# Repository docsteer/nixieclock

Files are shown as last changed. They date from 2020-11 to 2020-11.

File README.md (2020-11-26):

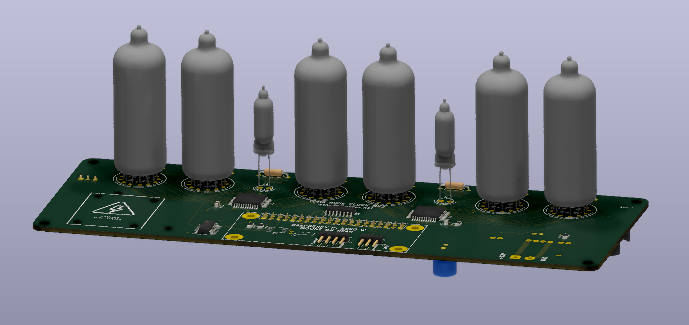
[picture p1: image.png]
Image of Clock


# Toms Nixie Clock
This project includes software and hardware designs for a nixie clock based on Raspberry Pi Zero W and IN14 tubes.

The design has hour, minute and second displays, separator digits (IN-1 indicators), and RGB LED underlighting of the tubes.

# Hardware
The hardware folder includes the PCB design files (KiCad format), and a bill of materials with component links to Mouser electronics.

# Software
The software is a Python script that runs on a standard installation of Raspian on a raspberry pi zero W.

It drives the tubes, and controls the LED underlighting based on astrononical time, pre-dawn, after dawn, after noon, after sunset)

It requires the following libraries (which you can install with ```pip install xxx```):

- spidev
- astral
- pytz
- neopixel

# Enclosure
The enclosure design is for laser-cut plywood with suitable openings for the tubes, indicators and support hardware

# License
This project is licensed under a Creative Commons Zero license. Feel free to remix and use as you please.

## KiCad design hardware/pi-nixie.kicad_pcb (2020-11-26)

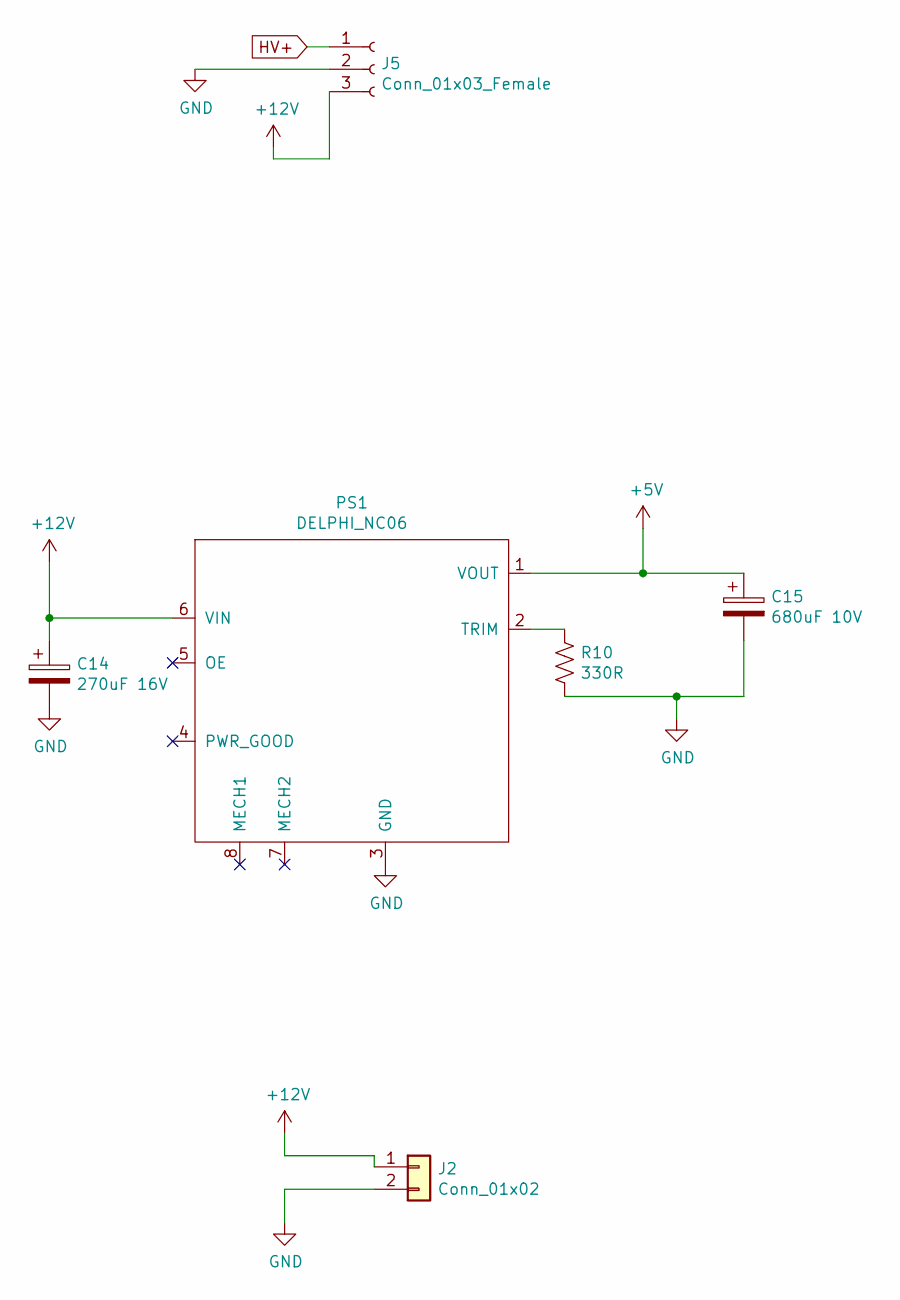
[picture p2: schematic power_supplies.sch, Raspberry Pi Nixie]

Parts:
C14: 270uF 16V; CP_Radial_D6.3mm_P2.50mm; Mouser P/N 232-16ZLJ270M6.3X11
C15: 680uF 10V; CP_Radial_D8.0mm_P3.50mm; Mouser P/N 710-860010274013
J2: Conn_01x02; SolderWirePad_1x02_P5.08mm_Drill1.5mm
J5: Conn_01x03_Female; PinHeader_1x03_P2.54mm_Vertical
PS1: DELPHI_NC06; DELPHI_NC06_REGULATOR
R10: 330R; R_1206_3216Metric_Pad1.42x1.75mm_HandSolder

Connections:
+5V: C15.1, PS1.1 (VOUT); also elsewhere on the board
+12V: C14.1, J2.1, J5.3, PS1.6 (VIN); also elsewhere on the board
GND: C14.2, C15.2, J2.2, J5.2, PS1.3 (GND), R10.2; also elsewhere on the board
HV+: J5.1; also elsewhere on the board
unnamed: PS1.2 (TRIM), R10.1

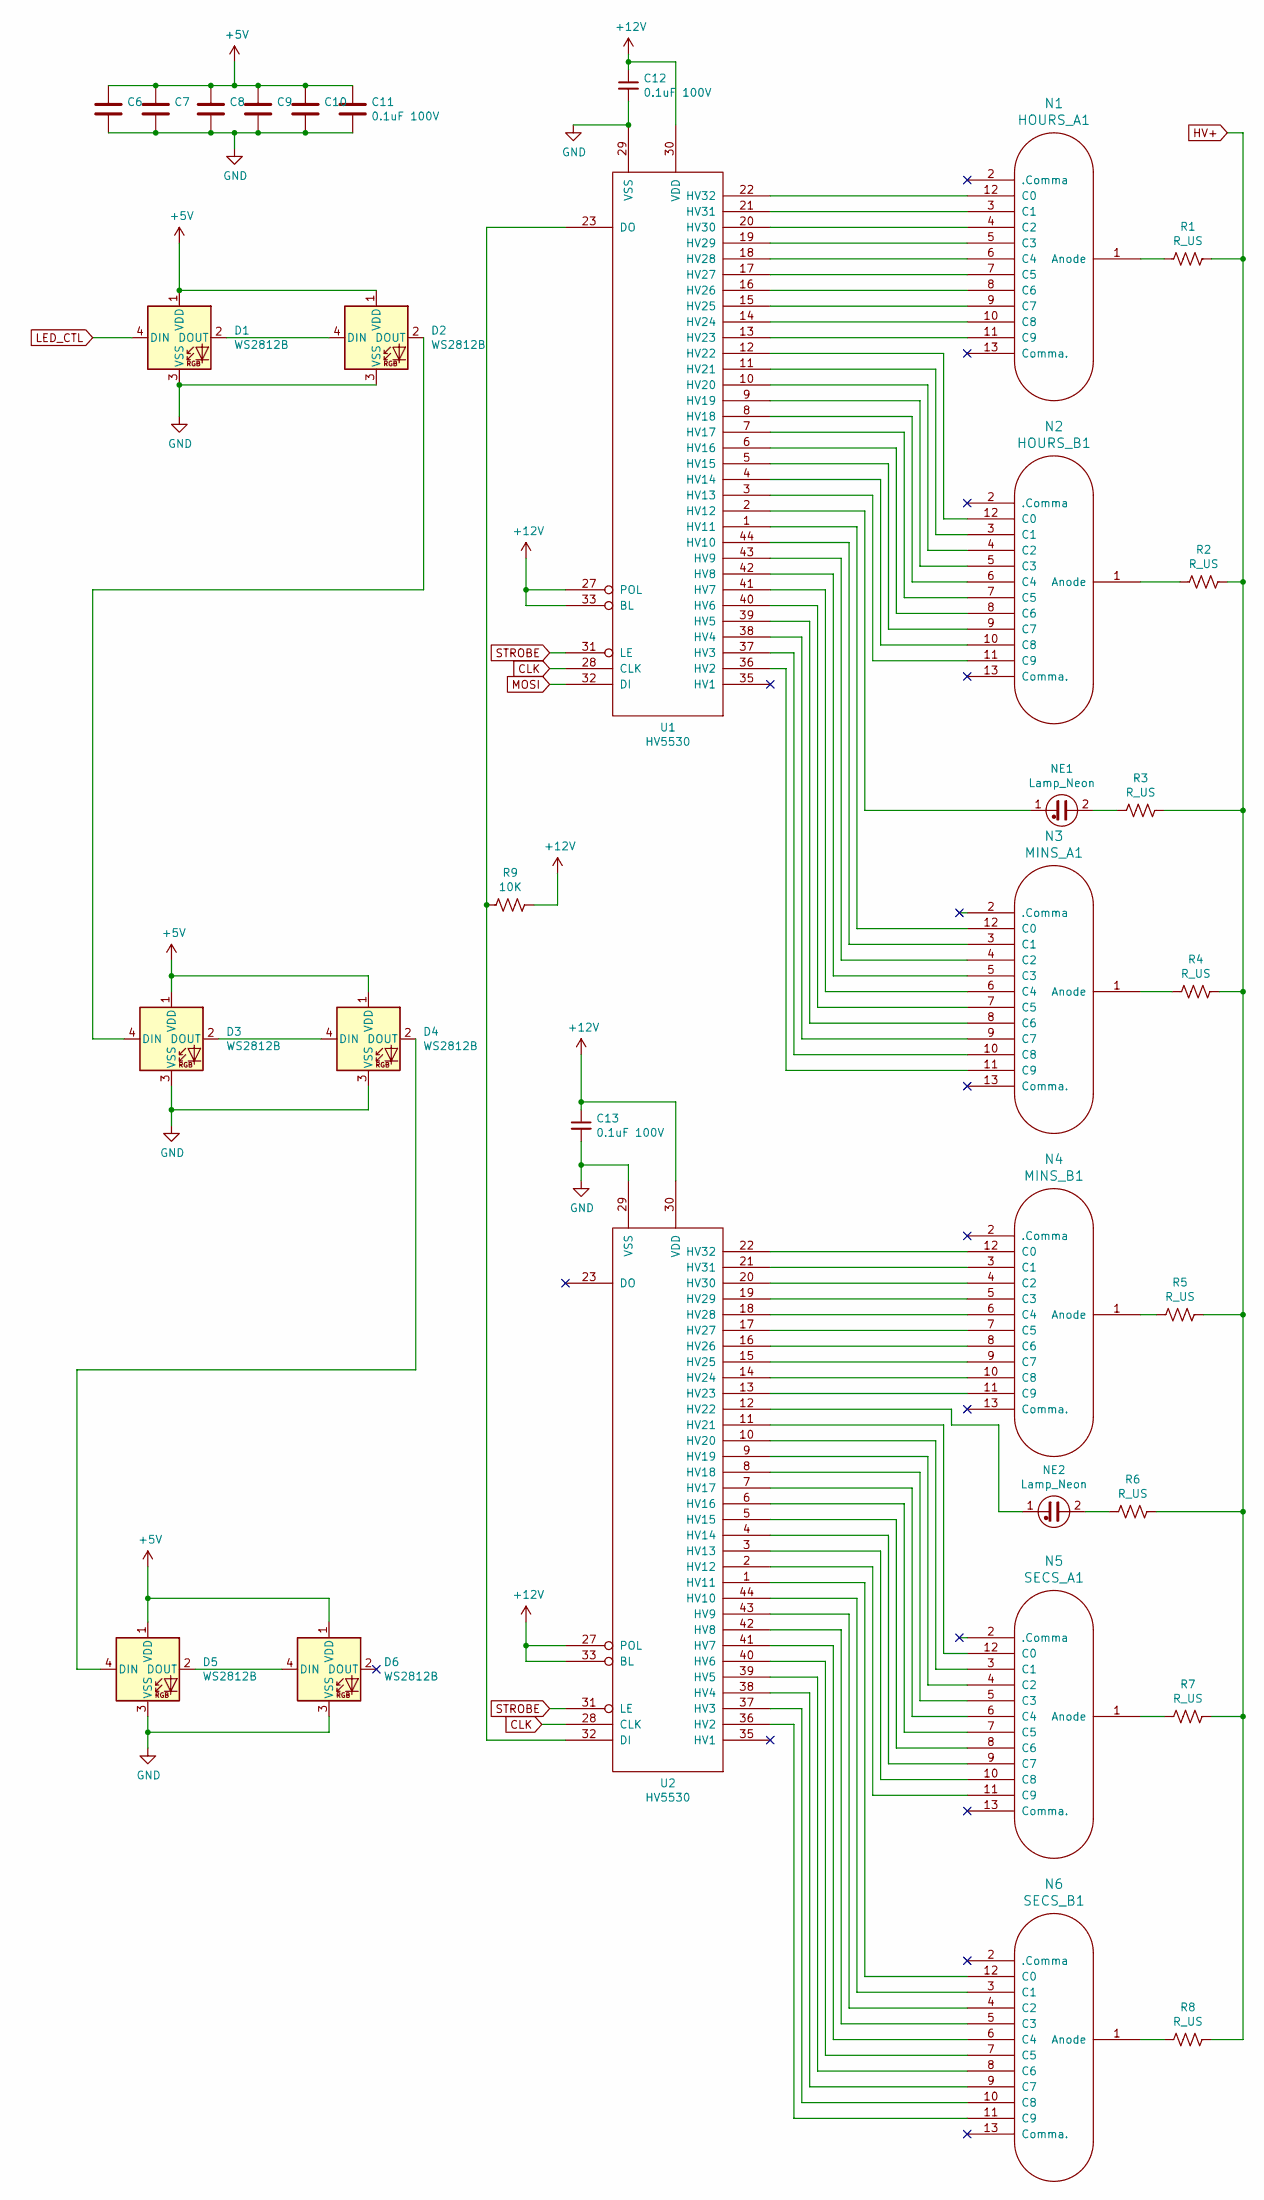
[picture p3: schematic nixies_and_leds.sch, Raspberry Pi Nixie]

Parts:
C6, C7, C8, C9, C10, C11, C12, C13: 0.1uF 100V; C_0805_2012Metric; Mouser P/N 710-885012207128
D1, D2, D3, D4, D5, D6: WS2812B; LED_WS2812B_PLCC4_5.0x5.0mm_P3.2mm; Mouser P/N 474-COM-13667
N1: HOURS_A1; IN-14-mod
N2: HOURS_B1; IN-14-mod
N3: MINS_A1; IN-14-mod
N4: MINS_B1; IN-14-mod
N5: SECS_A1; IN-14-mod
N6: SECS_B1; IN-14-mod
NE1, NE2: Lamp_Neon; IN-3
R1, R2, R3, R4, R5, R6, R7, R8: R_US; R_Axial_DIN0207_L6.3mm_D2.5mm_P10.16mm_Horizontal
R9: 10K; R_1206_3216Metric_Pad1.42x1.75mm_HandSolder
U1, U2: HV5530; PQFP-44_10x10mm_P0.8mm; Mouser P/N 689-HV5530PG-G

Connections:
+5V: C6.1, C7.1, C8.1, C9.1, C10.1, C11.1, D1.1 (VDD), D2.1 (VDD), D3.1 (VDD), D4.1 (VDD), D5.1 (VDD), D6.1 (VDD); also elsewhere on the board
+12V: C12.1, C13.1, R9.1, U1.27 (POL), U1.30 (VDD), U1.33 (BL), U2.27 (POL), U2.30 (VDD), U2.33 (BL); also elsewhere on the board
CLK: U1.28 (CLK), U2.28 (CLK); also elsewhere on the board
GND: C6.2, C7.2, C8.2, C9.2, C10.2, C11.2, C12.2, C13.2, D1.3 (VSS), D2.3 (VSS), D3.3 (VSS), D4.3 (VSS), D5.3 (VSS), D6.3 (VSS), U1.29 (VSS), U2.29 (VSS); also elsewhere on the board
HV+: R1.1, R2.1, R3.1, R4.1, R5.1, R6.1, R7.1, R8.1; also elsewhere on the board
LED_CTL: D1.4 (DIN); also elsewhere on the board
MOSI: U1.32 (DI); also elsewhere on the board
unnamed: D1.2 (DOUT), D2.4 (DIN)
unnamed: D2.2 (DOUT), D3.4 (DIN)
unnamed: D3.2 (DOUT), D4.4 (DIN)
unnamed: D4.2 (DOUT), D5.4 (DIN)
unnamed: D5.2 (DOUT), D6.4 (DIN)
unnamed: N1.1 (Anode), R1.2
unnamed: N1.3 (C1), U1.21 (HV31)
unnamed: N1.4 (C2), U1.20 (HV30)
unnamed: N1.5 (C3), U1.19 (HV29)
unnamed: N1.6 (C4), U1.18 (HV28)
unnamed: N1.7 (C5), U1.17 (HV27)
unnamed: N1.8 (C6), U1.16 (HV26)
unnamed: N1.9 (C7), U1.15 (HV25)
unnamed: N1.10 (C8), U1.14 (HV24)
unnamed: N1.11 (C9), U1.13 (HV23)
unnamed: N1.12 (C0), U1.22 (HV32)
unnamed: N2.1 (Anode), R2.2
unnamed: N2.3 (C1), U1.11 (HV21)
unnamed: N2.4 (C2), U1.10 (HV20)
unnamed: N2.5 (C3), U1.9 (HV19)
unnamed: N2.6 (C4), U1.8 (HV18)
unnamed: N2.7 (C5), U1.7 (HV17)
unnamed: N2.8 (C6), U1.6 (HV16)
unnamed: N2.9 (C7), U1.5 (HV15)
unnamed: N2.10 (C8), U1.4 (HV14)
unnamed: N2.11 (C9), U1.3 (HV13)
unnamed: N2.12 (C0), U1.12 (HV22)
unnamed: N3.1 (Anode), R4.2
unnamed: N3.3 (C1), U1.44 (HV10)
unnamed: N3.4 (C2), U1.43 (HV9)
unnamed: N3.5 (C3), U1.42 (HV8)
unnamed: N3.6 (C4), U1.41 (HV7)
unnamed: N3.7 (C5), U1.40 (HV6)
unnamed: N3.8 (C6), U1.39 (HV5)
unnamed: N3.9 (C7), U1.38 (HV4)
unnamed: N3.10 (C8), U1.37 (HV3)
unnamed: N3.11 (C9), U1.36 (HV2)
unnamed: N3.12 (C0), U1.1 (HV11)
unnamed: N4.1 (Anode), R5.2
unnamed: N4.3 (C1), U2.21 (HV31)
unnamed: N4.4 (C2), U2.20 (HV30)
unnamed: N4.5 (C3), U2.19 (HV29)
unnamed: N4.6 (C4), U2.18 (HV28)
unnamed: N4.7 (C5), U2.17 (HV27)
unnamed: N4.8 (C6), U2.16 (HV26)
unnamed: N4.9 (C7), U2.15 (HV25)
unnamed: N4.10 (C8), U2.14 (HV24)
unnamed: N4.11 (C9), U2.13 (HV23)
unnamed: N4.12 (C0), U2.22 (HV32)
unnamed: N5.1 (Anode), R7.2
unnamed: N5.3 (C1), U2.10 (HV20)
unnamed: N5.4 (C2), U2.9 (HV19)
unnamed: N5.5 (C3), U2.8 (HV18)
unnamed: N5.6 (C4), U2.7 (HV17)
unnamed: N5.7 (C5), U2.6 (HV16)
unnamed: N5.8 (C6), U2.5 (HV15)
unnamed: N5.9 (C7), U2.4 (HV14)
unnamed: N5.10 (C8), U2.3 (HV13)
unnamed: N5.11 (C9), U2.2 (HV12)
unnamed: N5.12 (C0), U2.11 (HV21)
unnamed: N6.1 (Anode), R8.2
unnamed: N6.3 (C1), U2.44 (HV10)
unnamed: N6.4 (C2), U2.43 (HV9)
unnamed: N6.5 (C3), U2.42 (HV8)
unnamed: N6.6 (C4), U2.41 (HV7)
unnamed: N6.7 (C5), U2.40 (HV6)
unnamed: N6.8 (C6), U2.39 (HV5)
unnamed: N6.9 (C7), U2.38 (HV4)
unnamed: N6.10 (C8), U2.37 (HV3)
unnamed: N6.11 (C9), U2.36 (HV2)
unnamed: N6.12 (C0), U2.1 (HV11)
unnamed: NE1.1, U1.2 (HV12)
unnamed: NE1.2, R3.2
unnamed: NE2.1, U2.12 (HV22)
unnamed: NE2.2, R6.2
unnamed: R9.2, U1.23 (DO), U2.32 (DI)
STROBE: U1.31 (LE), U2.31 (LE); also elsewhere on the board

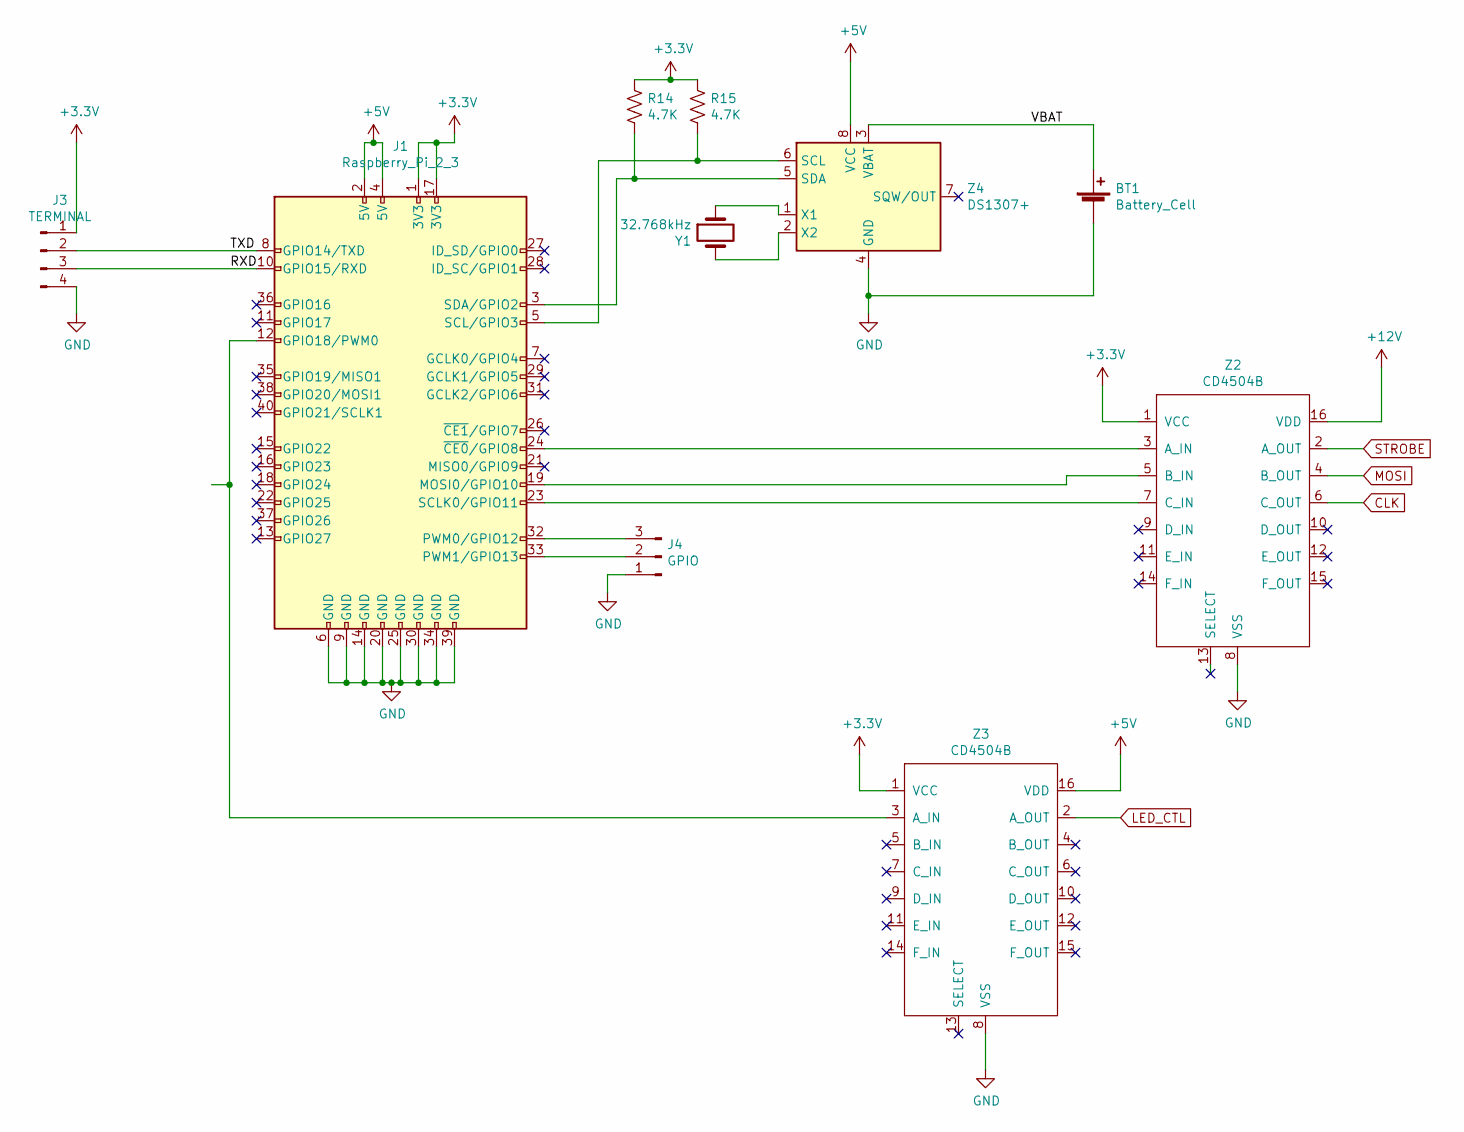
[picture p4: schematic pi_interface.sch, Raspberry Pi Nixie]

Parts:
BT1: Battery_Cell; BatteryHolder_Keystone_1058_1x2032
J1: Raspberry_Pi_2_3; Raspberry_Pi_Zero
J3: TERMINAL; PinHeader_1x04_P2.54mm_Horizontal
J4: GPIO; PinHeader_1x03_P2.54mm_Horizontal
R14, R15: 4.7K; R_1206_3216Metric_Pad1.42x1.75mm_HandSolder
Y1: 32.768kHz; Crystal_DS26_D2.0mm_L6.0mm_Horizontal; Mouser P/N 520-TFC2X6-X
Z2, Z3: CD4504B; SOIC-16_4.55x10.3mm_P1.27mm; Mouser P/N 595-CD4504BM96
Z4: DS1307+; SO-8_3.9x4.9mm_P1.27mm; Mouser P/N 700-DS1307Z

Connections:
+3V3: J1.1 (3V3), J1.17 (3V3), J3.1, R14.1, R15.1, Z2.1 (VCC), Z3.1 (VCC)
+5V: J1.2 (5V), J1.4 (5V), Z3.16 (VDD), Z4.8 (VCC); also elsewhere on the board
+12V: Z2.16 (VDD); also elsewhere on the board
/Pi Interface/RXD: J1.10 (GPIO15/RXD), J3.3
/Pi Interface/TXD: J1.8 (GPIO14/TXD), J3.2
/Pi Interface/VBAT: BT1.1 (+), Z4.3 (VBAT)
CLK: Z2.6 (C_OUT); also elsewhere on the board
GND: BT1.2 (-), J1.6 (GND), J1.9 (GND), J1.14 (GND), J1.20 (GND), J1.25 (GND), J1.30 (GND), J1.34 (GND), J1.39 (GND), J3.4, J4.1, Z2.8 (VSS), Z3.8 (VSS), Z4.4 (GND); also elsewhere on the board
LED_CTL: Z3.2 (A_OUT); also elsewhere on the board
MOSI: Z2.4 (B_OUT); also elsewhere on the board
unnamed: J1.3 (SDA/GPIO2), R14.2, Z4.5 (SDA)
unnamed: J1.5 (SCL/GPIO3), R15.2, Z4.6 (SCL)
unnamed: J1.12 (GPIO18/PWM0), Z3.3 (A_IN)
unnamed: J1.19 (MOSI0/GPIO10), Z2.5 (B_IN)
unnamed: J1.23 (SCLK0/GPIO11), Z2.7 (C_IN)
unnamed: J1.24 (~CE0~/GPIO8), Z2.3 (A_IN)
unnamed: J1.32 (PWM0/GPIO12), J4.3
unnamed: J1.33 (PWM1/GPIO13), J4.2
unnamed: Y1.1, Z4.1 (X1)
unnamed: Y1.2, Z4.2 (X2)
STROBE: Z2.2 (A_OUT); also elsewhere on the board

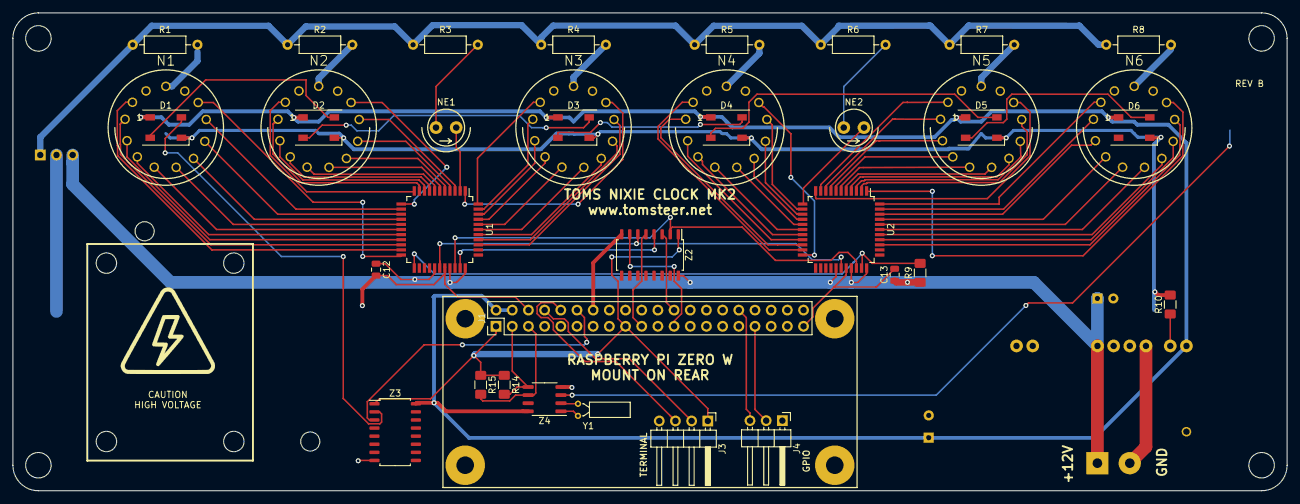
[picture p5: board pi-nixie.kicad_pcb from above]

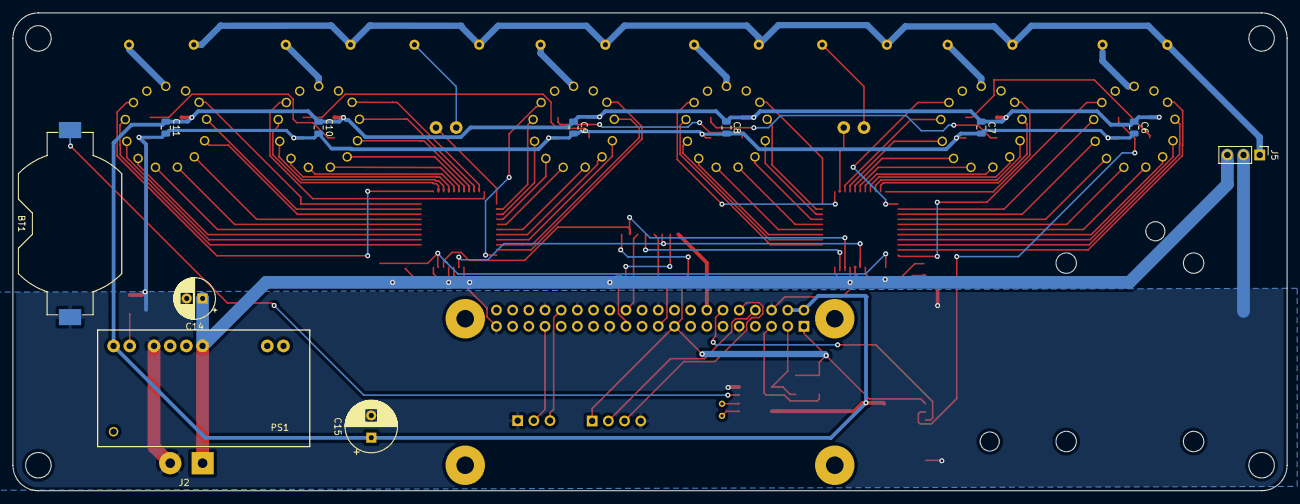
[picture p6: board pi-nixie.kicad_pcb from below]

Board: 2 copper layers, 200.0 x 75.0 mm, 49 parts (12 on the bottom side), 99 nets.

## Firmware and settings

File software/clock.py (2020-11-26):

import time
import spidev
from _rpi_ws281x import *
from neopixel import *

from astral import LocationInfo
from astral.sun import sun
from datetime import datetime, timezone, date
from astral.geocoder import database, lookup
import pytz
import sys

# LED strip configuration:
LED_COUNT      = 6
LED_PIN        = 18      # GPIO pin connected to the pixels (18 uses PWM!).
LED_FREQ_HZ    = 800000  # LED signal frequency in hertz (usually 800khz)
LED_DMA        = 10      # DMA channel to use for generating signal (try 10)
LED_BRIGHTNESS = 255     # Set to 0 for darkest and 255 for brightest
LED_INVERT     = False   # True to invert the signal (when using NPN transistor level shift)
LED_CHANNEL    = 0       # set to '1' for GPIOs 13, 19, 41, 45 or 53

COLOR_PRE_DAWN = Color(0, 0, 20)
COLOR_PRE_NOON =  Color(40, 44, 0)
COLOR_PRE_SUNSET = Color(0, 35, 27)
COLOR_AFTER_SUNSET = Color(0, 0, 50)

# Reverse table is used because we don't know how to change bit-order on SPI settings
BitReverseTable = [0x00, 0x80, 0x40, 0xC0, 0x20, 0xA0, 0x60, 0xE0, 0x10, 0x90, 0x50, 0xD0, 0x30, 0xB0, 0x70, 0xF0,
                      0x08, 0x88, 0x48, 0xC8, 0x28, 0xA8, 0x68, 0xE8, 0x18, 0x98, 0x58, 0xD8, 0x38, 0xB8, 0x78, 0xF8,
                      0x04, 0x84, 0x44, 0xC4, 0x24, 0xA4, 0x64, 0xE4, 0x14, 0x94, 0x54, 0xD4, 0x34, 0xB4, 0x74, 0xF4,
                      0x0C, 0x8C, 0x4C, 0xCC, 0x2C, 0xAC, 0x6C, 0xEC, 0x1C, 0x9C, 0x5C, 0xDC, 0x3C, 0xBC, 0x7C, 0xFC,
                      0x02, 0x82, 0x42, 0xC2, 0x22, 0xA2, 0x62, 0xE2, 0x12, 0x92, 0x52, 0xD2, 0x32, 0xB2, 0x72, 0xF2,
                      0x0A, 0x8A, 0x4A, 0xCA, 0x2A, 0xAA, 0x6A, 0xEA, 0x1A, 0x9A, 0x5A, 0xDA, 0x3A, 0xBA, 0x7A, 0xFA,
                      0x06, 0x86, 0x46, 0xC6, 0x26, 0xA6, 0x66, 0xE6, 0x16, 0x96, 0x56, 0xD6, 0x36, 0xB6, 0x76, 0xF6,
                      0x0E, 0x8E, 0x4E, 0xCE, 0x2E, 0xAE, 0x6E, 0xEE, 0x1E, 0x9E, 0x5E, 0xDE, 0x3E, 0xBE, 0x7E, 0xFE,
                      0x01, 0x81, 0x41, 0xC1, 0x21, 0xA1, 0x61, 0xE1, 0x11, 0x91, 0x51, 0xD1, 0x31, 0xB1, 0x71, 0xF1,
                      0x09, 0x89, 0x49, 0xC9, 0x29, 0xA9, 0x69, 0xE9, 0x19, 0x99, 0x59, 0xD9, 0x39, 0xB9, 0x79, 0xF9,
                      0x05, 0x85, 0x45, 0xC5, 0x25, 0xA5, 0x65, 0xE5, 0x15, 0x95, 0x55, 0xD5, 0x35, 0xB5, 0x75, 0xF5,
                      0x0D, 0x8D, 0x4D, 0xCD, 0x2D, 0xAD, 0x6D, 0xED, 0x1D, 0x9D, 0x5D, 0xDD, 0x3D, 0xBD, 0x7D, 0xFD,
                      0x03, 0x83, 0x43, 0xC3, 0x23, 0xA3, 0x63, 0xE3, 0x13, 0x93, 0x53, 0xD3, 0x33, 0xB3, 0x73, 0xF3,
                      0x0B, 0x8B, 0x4B, 0xCB, 0x2B, 0xAB, 0x6B, 0xEB, 0x1B, 0x9B, 0x5B, 0xDB, 0x3B, 0xBB, 0x7B, 0xFB,
                      0x07, 0x87, 0x47, 0xC7, 0x27, 0xA7, 0x67, 0xE7, 0x17, 0x97, 0x57, 0xD7, 0x37, 0xB7, 0x77, 0xF7,
                      0x0F, 0x8F, 0x4F, 0xCF, 0x2F, 0xAF, 0x6F, 0xEF, 0x1F, 0x9F, 0x5F, 0xDF, 0x3F, 0xBF, 0x7F, 0xFF]

# Set up astro location
city = lookup("Chicago", database())

# Set up SPI
bus = 0
device = 0
spi = spidev.SpiDev()
spi.open(bus, device)

# Set SPI speed and mode
spi.max_speed_hz = 500000
# Data on the falling edge
spi.mode = 0b01

def colorWipe(strip, color, wait_ms=50):
    """Wipe color across display a pixel at a time."""
    for i in range(strip.numPixels()):
        strip.setPixelColor(i, color)
        strip.show()
        time.sleep(wait_ms/1000.0)


DigitReverseTable = [9, 8, 7, 6, 5, 4, 3, 2, 1, 0]


def make_values(hours, minutes, seconds, sep1, sep2):
    assert hours>=0
    assert hours<=99
    assert minutes>=0
    assert minutes<=99
    assert seconds>=0
    assert seconds<=99

    hours_a = hours // 10
    hours_b = hours % 10
    mins_a = minutes // 10
    mins_b = minutes % 10
    secs_a = seconds // 10
    secs_b = seconds % 10

    # Shift all the values into one
    big_value = 0
    #big_value |= (1 << secs_b) << 53
    #big_value |= (1 << secs_a) << 43
    #big_value |= (1 << mins_b) << 32
    big_value |= (1 << DigitReverseTable[mins_a]) << 1
    big_value |= (1 << DigitReverseTable[hours_b]) << 12
    big_value |= (1 << DigitReverseTable[hours_a]) << 22

    
    if(sep1):
        big_value |= (1 << 11)
    if(sep2):
        big_value |= (1 << 40)

    # Split big_value into bytes
    bytes = big_value.to_bytes(8, 'big')

    spi.writebytes(bytes)
    

def run_clock():
    seps = True
    count = 60;
    while(True):
        localtime = time.localtime(time.time())
        make_values(localtime.tm_hour, localtime.tm_min, localtime.tm_sec, seps, seps)
        seps = not seps
        time.sleep(1)
	
        s = sun(city.observer, date=date.today(), tzinfo=city.timezone)

        count = count + 1


        if count>=60:
            count = 0
            # Update colours every min
            utc_dt = datetime.now(timezone.utc) # UTC time
            dt = utc_dt.astimezone() # local time
            if(dt < s["dawn"]):
                colorWipe(strip, COLOR_PRE_DAWN)
                print("It is before dawn")
            elif (dt  < s["noon"]):
                print("It is before noon")
                colorWipe(strip, COLOR_PRE_NOON)
            elif (dt  < s["sunset"]):
                print("It is before sunset")
                colorWipe(strip, COLOR_PRE_SUNSET)
            else:
                print("It is after sunset")
                colorWipe(strip, COLOR_AFTER_SUNSET)

# Create NeoPixel object with appropriate configuration.
strip = Adafruit_NeoPixel(LED_COUNT, LED_PIN, LED_FREQ_HZ, LED_DMA, LED_INVERT, LED_BRIGHTNESS, LED_CHANNEL)
# Intialize the library (must be called once before other functions).
strip.begin()

if len(sys.argv)==1:
   run_clock();

print("1: Test pattern 11:11:11, separators off")
print("2: Test pattern 99:99:99, separators off")
print("3: Test pattern 12:34:56, separators on")
print("4: Clock Operation")
print("5: All red")
print("6: All green")
print("7: All blue")
print("8: Color Tester")
print("9: Step digits")
print("10: Enter values")
choice = input("Select Option: ")
if(choice=="1"):
    make_values(11,11,11,False, False)
if(choice=="2"):
    make_values(99,99,99,False, False)
if(choice=="3"):
    make_values(12,34,56,True, True)
if(choice=="4"):
    run_clock()
if(choice=="5"):
    colorWipe(strip, Color(0,255,0))
if(choice=="6"):
    colorWipe(strip, Color(255,0,0))
if(choice=="7"):
    colorWipe(strip, Color(0,0,255))
if(choice=="8"):
    while True:
        color = input("Enter Color in R,G,B format, 0-255: ")
        list = color.split(",")
        colorWipe(strip, Color(int(list[0]), int(list[1]), int(list[2])))
if(choice=="9"):
    value = 1
    while True:
        bytes = input("Press enter: ")
        value = value << 1
        spi.writebytes(value.to_byte(8, 'big'))
        print(hex(value))
if(choice=="10"):
    while True:
        value = input("Enter hh,mm,ss: ")
        list = value.split(",")
        make_values(int(list[0]), int(list[1]), int(list[2]), False, False)
